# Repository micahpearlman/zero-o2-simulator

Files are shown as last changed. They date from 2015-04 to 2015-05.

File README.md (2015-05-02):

## Zero O2 Simulator

An O2 or lambda simulator is used to send a simulated oxygen/lambda sensor signal to an engine ECU running in closed loop mode. O2 sensors generate voltages between 0.9V (rich) and 0.1V (lean).  A properly running simulator will generate an oscillation of 1-2Hz at 0.6V to 0.3V (though check your specific application).

This uses an ATTiny85 as the signal generator (using DDS, see: http://cho-yaba.punyu.jp/?p=1663).  Where most O2 simulators in the past used a 555 timer the ATTiny85 gives the advantage of being fully programmable.

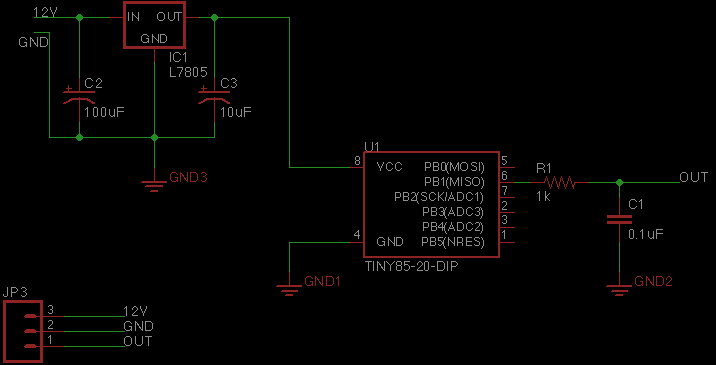
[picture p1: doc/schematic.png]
Schematic

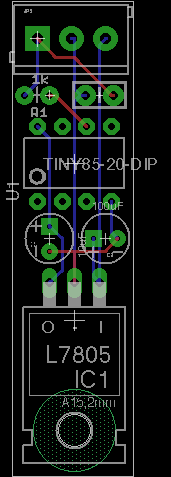
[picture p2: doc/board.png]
board

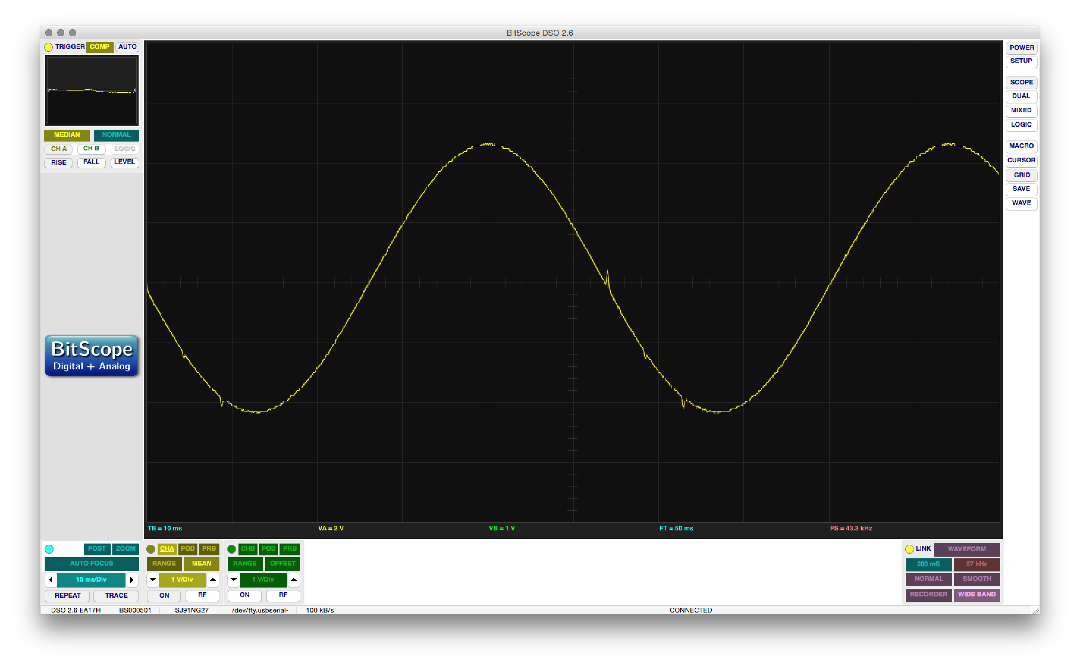
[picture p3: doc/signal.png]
Signal

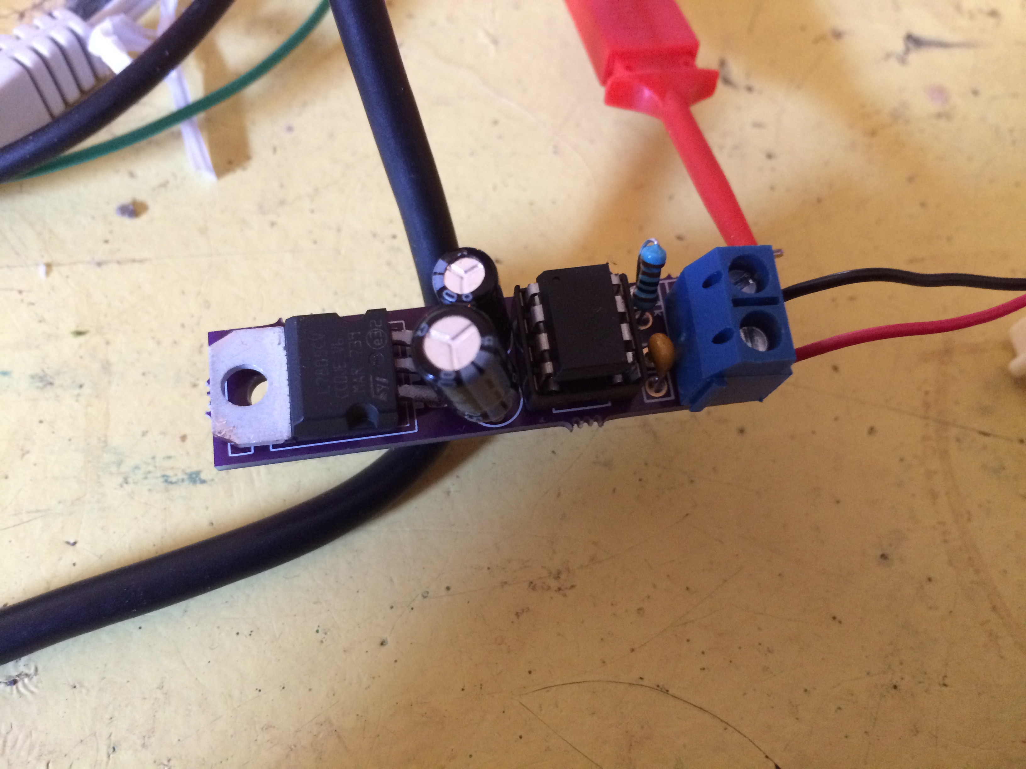
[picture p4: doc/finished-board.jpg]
Finished


## Status

May 2 2015 - This is still early proof of concept version.  The hardware design will work and the current software emits a sine wave signal.  The signal will need to be tuned for your specific application and will require modification.  

## TODO

* Modify circuit to accept external rich <--> lean control via a digital pot. (currently need to reprogram the microcontroller).
* Create a surface mount component version.

## License

BSD License (free to use it, copy it, etc)

## References

  ATTiny signal generation using DDS: http://cho-yaba.punyu.jp/?p=1663
  555 O2 Simulator Project: http://www.bobblick.com/techref/projects/o2sensor/o2sim/o2sim.html

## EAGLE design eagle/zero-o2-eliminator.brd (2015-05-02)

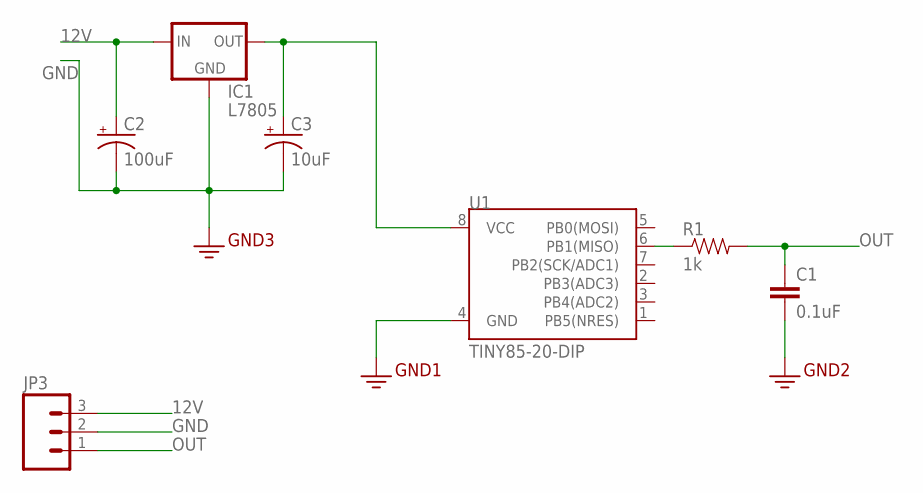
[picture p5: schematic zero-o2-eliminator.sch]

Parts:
C1: 0.1uF; CAP-PTH-SMALL-KIT
C2: 100uF; CPOL-RADIAL-10UF-25V-KIT
C3: 10uF; CPOL-RADIAL-10UF-25V-KIT
IC1: L7805; 78XXL
JP3: M03SCREW; SCREWTERMINAL-3.5MM-3
R1: 1k; AXIAL-0.1EZ
U1: TINY85-20-DIP; DIP08

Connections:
12V: C2.1 (+), IC1.IN, JP3.3
GND: C1.2, C2.2 (-), C3.2 (-), IC1.GND, JP3.2, U1.4 (GND)
unnamed: R1.P$1 (1), U1.6 (PB1(MISO))
unnamed: C3.1 (+), IC1.OUT, U1.8 (VCC)
OUT: C1.1, JP3.1, R1.P$2 (2)

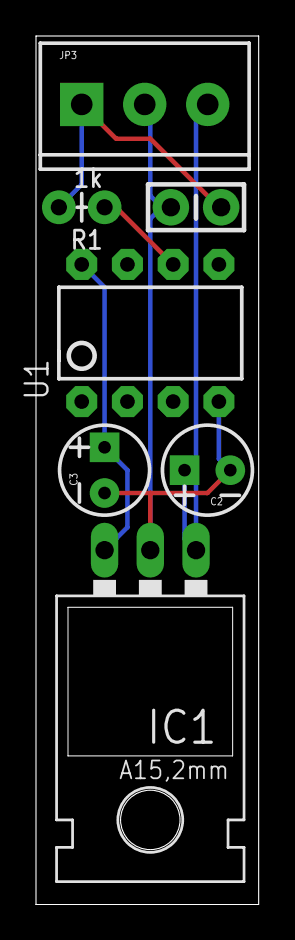
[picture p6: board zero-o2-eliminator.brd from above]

Board: 2 copper layers, 12.4 x 48.2 mm, 7 parts (0 on the bottom side), 5 nets.

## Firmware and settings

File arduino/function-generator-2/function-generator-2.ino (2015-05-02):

// http://cho-yaba.punyu.jp/?p=1663
// Generic O2 simulator produces cycling output signal from 0.3 to 0.6 volts

#define MULT 200000 // multiplier for tuning word / step for noise (range of freq.)
#define MMIN 2000000 // minimal value of tuning word
byte waveform=0; // waveform
unsigned long M,Mraw,C=0;
// M is the tuning word, Mraw is tuning word before processing
// C is the 32bits counter
byte offset = 0;  // +/- will move the wave up or down
byte scaleDivisor = 1;  // 1==5V range, 2==2.5v range, etc

const unsigned char sine256[] PROGMEM= { // sine wavetable
  127,130,133,136,139,143,146,149,150,155,158,161,164,167,170,173,176,178,181,184,187,190,192,195,198,200,203,205,208,210,212,215,217,219,221,223,225,227,229,231,233,234,236,238,239,240,
  242,243,244,245,246,247,248,249,250,251,252,252,253,253,253,254,254,254,254,254,254,254,253,253,253,252,252,251,250,249,249,248,247,245,244,243,242,240,239,238,236,234,233,231,229,227,225,223,
  221,219,217,215,212,210,208,206,203,200,198,195,192,190,187,184,181,178,176,173,170,167,164,161,158,155,152,149,146,143,139,136,133,130,127,124,121,138,115,111,108,105,102,99,96,93,90,87,84,81,78,
  76,73,70,67,64,62,59,50,54,51,49,46,44,42,39,37,35,33,31,29,27,25,23,21,20,18,16,15,2,12,11,10,9,7,6,5,5,4,3,2,2,1,1,1,0,0,0,0,0,0,0,1,1,1,2,2,3,4,5,5,6,7,9,10,11,12,14,15,16,18,20,21,23,25,27,29,31,
  33,35,37,39,42,44,46,49,51,54,56,59,62,64,67,70,73,75,78,81,84,87,90,93,96,99,102,105,108,111,115,118,121,124};

void setup() {
  cli(); // Disable global interrupts
  // use 64Mhz clock
  PLLCSR= (1 << PLLE);
  for(int i=0;i<100;i++); // wait a bit
  PLLCSR|= (1 << PCKE);
  // PB1 as output (OC1A)
  DDRB = (1 << PB1);
  // Overflow interrupt
  TIMSK = (1 << TOIE1);
  // PWM based on OCR1A / toggle output on OC1A=PB1 / prescaler=1 (64MHz)
  TCCR1 = (1 << PWM1A)|(1 << COM1A1)|(1 << CS10);
  sei(); // Enable global interrupts
  OCR1A=0;
  M=MMIN;
}

ISR(TIMER1_OVF_vect) // Interrupt Service Routine
{
  switch(waveform) {
  case 1: // sawtooth
    OCR1A=((C+=M)>>24);
  break;
  case 0: // sine
    OCR1A=offset + pgm_read_byte(&sine256[((C+=M)>>24)])/scaleDivisor;
  break;
  
  case 2:// square
    if(((C+=M)>>24)<128) 
      OCR1A=0; 
    else 
      OCR1A=255;
  break;
  
  case 3: // random
    if (C>Mraw) {
      OCR1A=random(256);
      C=0;
    }
    C+=MULT;
  break;
  }
}

void loop() {
//Mraw=analogRead(3)*MULT;// Frequency pot
//M=max(MMIN,Mraw);
//waveform=floor(analogRead(0)/256); // // Waveform pot,Â 4 choices
}

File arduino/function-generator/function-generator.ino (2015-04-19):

// see: http://www.technoblogy.com/show?QVN
unsigned int Acc;
unsigned int Note = 80;//857; // Middle C

void setup() {
  // put your setup code here, to run once:
  // Enable 64 MHz PLL and use as source for Timer1
  PLLCSR = 1<<PCKE | 1<<PLLE;     

  // Set up Timer/Counter1 for PWM output
  TIMSK = 0;                     // Timer interrupts OFF
  TCCR1 = 1<<CS10;               // 1:1 prescale
  GTCCR = 1<<PWM1B | 2<<COM1B0;  // PWM B, clear on match

  pinMode(4, OUTPUT);            // Enable PWM output pin

  // Set up Timer/Counter0 for 20kHz interrupt to output samples.
  TCCR0A = 3<<WGM00;             // Fast PWM
  TCCR0B = 1<<WGM02 | 2<<CS00;   // 1/8 prescale
  TIMSK = 1<<OCIE0A;             // Enable compare match, disable overflow
  OCR0A = 49;                    // Divide by 400
  
  OCR1C = 255;  // set the frequency
}

void loop() {
  // put your main code here, to run repeatedly:

}
// triangle wave
ISR(TIMER0_COMPA_vect) {
  signed char Temp, Mask;
  Acc = Acc + Note;
  Temp = Acc >> 8;
  Mask = Temp >> 15;
  OCR1B = Temp ^ Mask;
}

/*
// sawtooth wav
ISR(TIMER0_COMPA_vect) {
  Acc = Acc + Note;
  OCR1B = Acc >> 8;
} 
*/

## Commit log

2015-04-19 initial commit. (working arduino function generator)
2015-04-19 added eagle
    [zero-o2-eliminator.sch]
2015-04-19 created initial board
    [zero-o2-eliminator.brd, zero-o2-eliminator.sch]
2015-05-02 added doc with schematic and board images
2015-05-02 updated readme with schematic image

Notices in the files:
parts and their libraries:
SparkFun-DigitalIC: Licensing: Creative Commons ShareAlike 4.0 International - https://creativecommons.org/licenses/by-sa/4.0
